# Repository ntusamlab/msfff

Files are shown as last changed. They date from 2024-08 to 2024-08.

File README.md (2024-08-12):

# minimizedsupportfff

## Project Title
Novel Fused Filament Fabrication System for Additive Manufacturing with Minimized Support Structures
<br />
<br />
## Project Description
The algorithm can modify the G-code to cooperate with the discrete platform, which includes support-eliminating, path-rearranging, and adding the lifting motions.
<br />
<br />
## File List and Descriptions
CAD_files:
| Name | Description |
| --- | --- |
| CAD_files | the whole model used in the program |
| fan_holder | the extruder module |
| modules | the servo and other ready-made parts |
| plane_unit | the part of the platform |
| ladder/bridge/blade | the part of case study |
| code | the whole code in algorithm |
| test_main | main program to modify g-code |
| test_3dprint_arduino | program to start the printing and communicate with printer |
| test_platform_raise_correction | correction g-code before printing |
| requirements | library for python |
| module | all functions required |
| test_table | database of the experiment |
<br />
<br />

## Steps 

Steps in order to run the code. 

1. please start from downloading or cloning the repository and all the way to run the code with required input data
2. use Cura to slice the stl. file and save the result into the 'gcode_cura'
3. run 'test_main.py' to modify the g-code and the result will automatically saved into 'test_output'
4. put the modified g-code into the SD card and set it into the printer
5. run 'test_3dprint_arduino.py' to start printing
6. The printer will pause as the platform is going to be lifted
7. after printing, the total time and support time will be shown

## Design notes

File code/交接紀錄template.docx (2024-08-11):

紀錄之前請將紅色說明文字刪除

研究題目/儀器種類：

研究題目名稱或儀器名稱(請註記產編)

記錄日期：

記錄人員與聯絡資訊：

原負責人與記錄人員名字與聯絡資訊(email)

原負責人：黃中道 r11522715@ntu.edu.tw

操作事前準備(硬體)：

需要操作系統前之準備(著重在硬體部分 例如燈光或背景等) 若無則寫無

操作事情準備(軟體)：

需要操作系統前之準備(著重在軟體部分) 若無則寫無

原負責人請將最後版本的軟體與所用到的照片/數據放到github並附上下載網址

交接的人請務必下載好最後版本的軟體與所用到的照片/數據

**8/12號老師會說明github管理

系統操作步驟：

請詳細記錄每一步 包含從開哪個程式 先處理哪個檔案

到如何操作整個系統 如何「收集」、「處理」與「紀錄」數據

每一步可以的話請附上圖片

特別須知/發生過的問題：

若曾經發生過特別的問題或是特殊的操作要點請詳細記錄

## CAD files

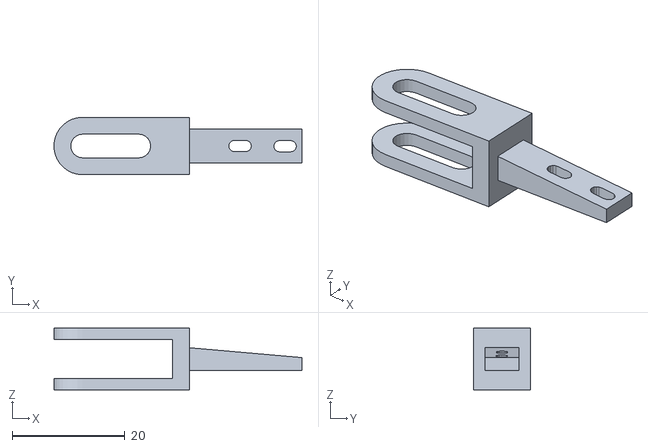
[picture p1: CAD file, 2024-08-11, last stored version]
CAD_files/fan_holder_0227/fan_holder_0301_05.stl
44.1 x 10.2 x 11.0

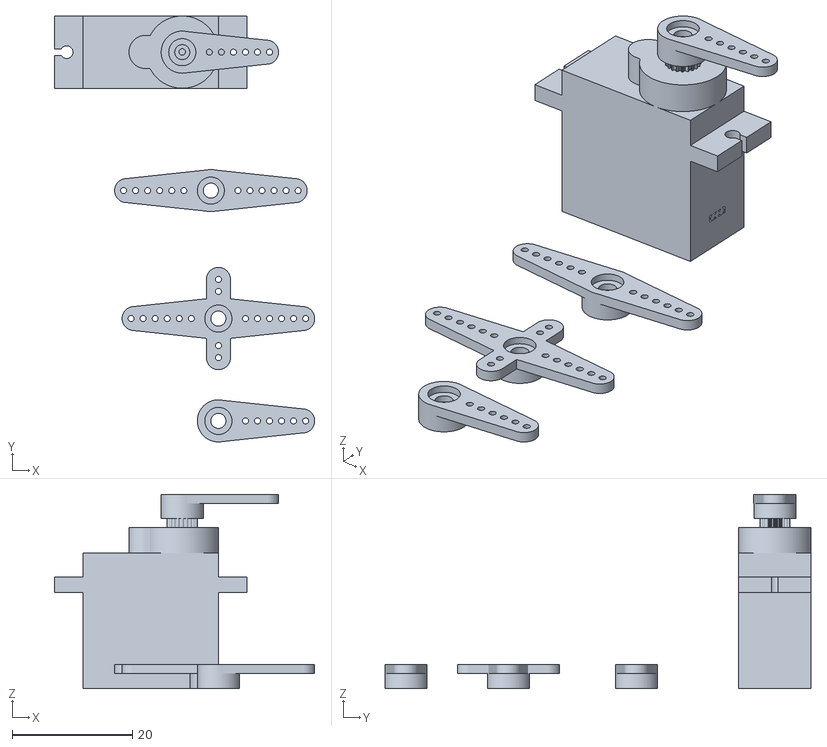
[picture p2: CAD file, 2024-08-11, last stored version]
CAD_files/modules/Servo SG90 Model.stl
43.2 x 70.8 x 32.2

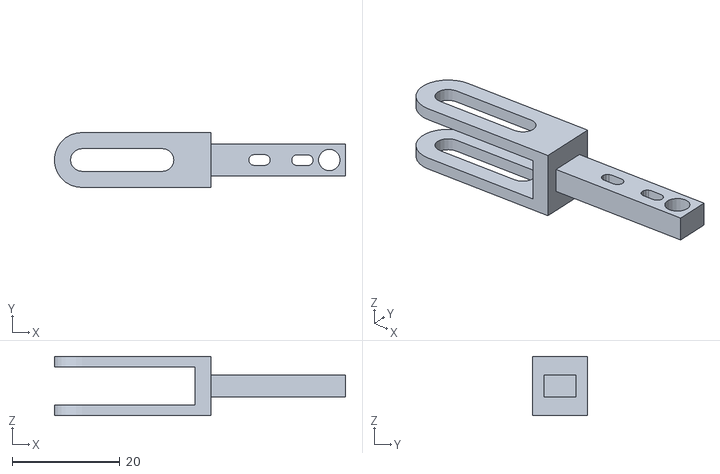
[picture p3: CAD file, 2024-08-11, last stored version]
CAD_files/fan_holder_0227/fan_holder_0301.stl
54.1 x 10.2 x 11.0

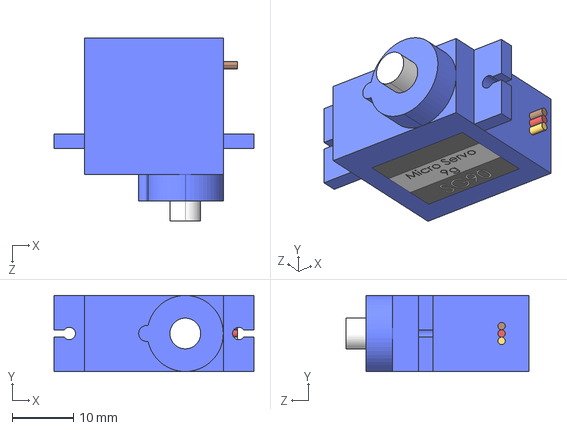
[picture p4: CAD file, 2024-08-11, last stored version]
CAD_files/modules/SG90 Micro Servo - 3D Model.STEP
32.6 x 12.4 x 29.9 mm

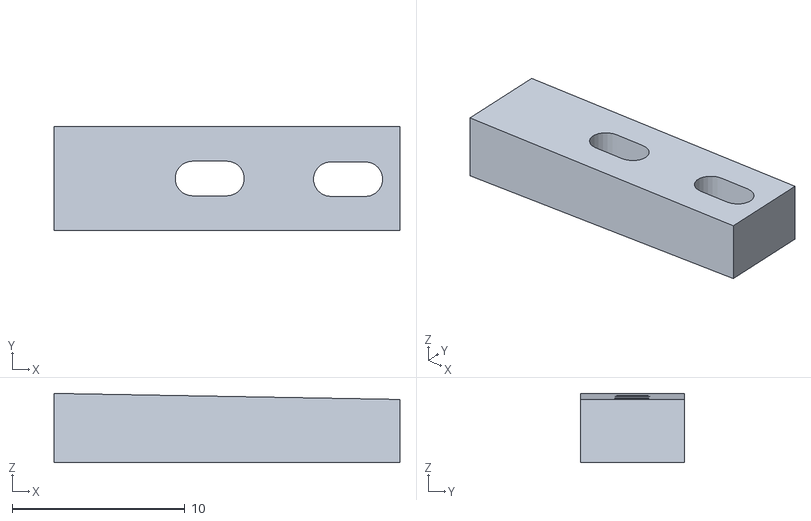
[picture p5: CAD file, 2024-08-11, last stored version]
CAD_files/fan_holder_0227/fan_holder_0301_01.stl
20.0 x 6.00 x 4.00

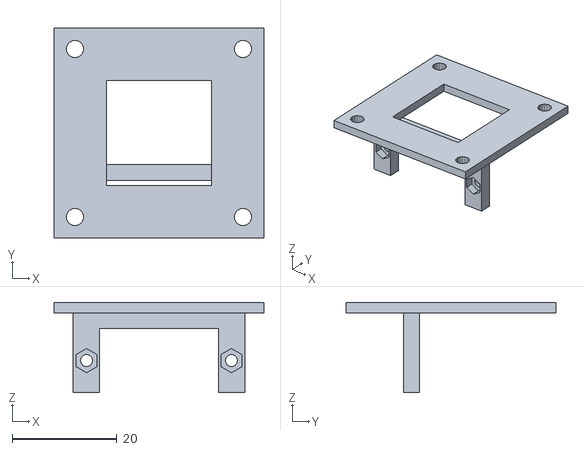
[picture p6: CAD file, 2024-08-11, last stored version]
CAD_files/fan_holder_0227/SG90_holder_0213.stl
40.0 x 40.0 x 17.2

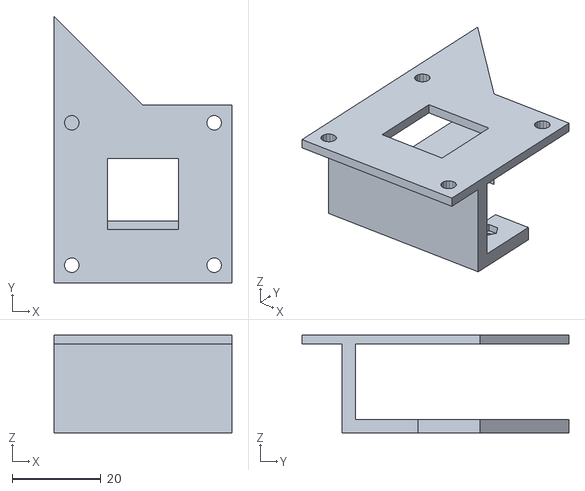
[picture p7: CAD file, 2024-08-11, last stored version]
CAD_files/fan_holder_0227/SG90_holder_0206.stl
40.0 x 60.0 x 22.0

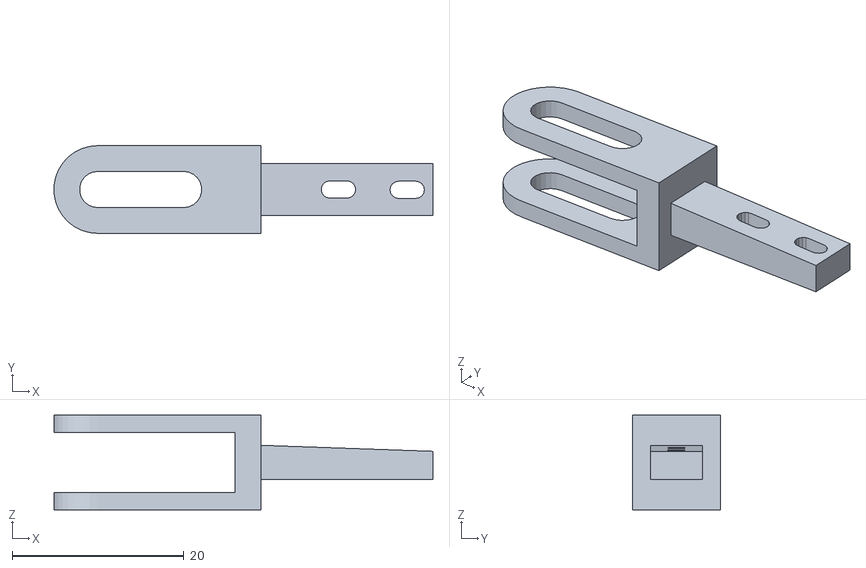
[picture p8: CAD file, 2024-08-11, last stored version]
CAD_files/fan_holder_0227/fan_holder_0301_02.stl
44.1 x 10.2 x 11.0

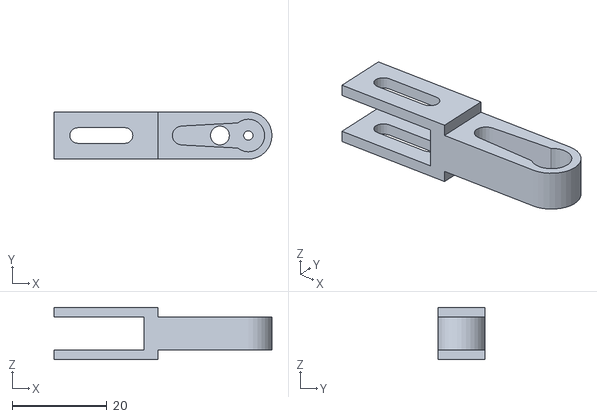
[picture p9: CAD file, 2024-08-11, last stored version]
CAD_files/fan_holder_0227/fan_holder_0301_10.stl
46.0 x 10.0 x 11.0

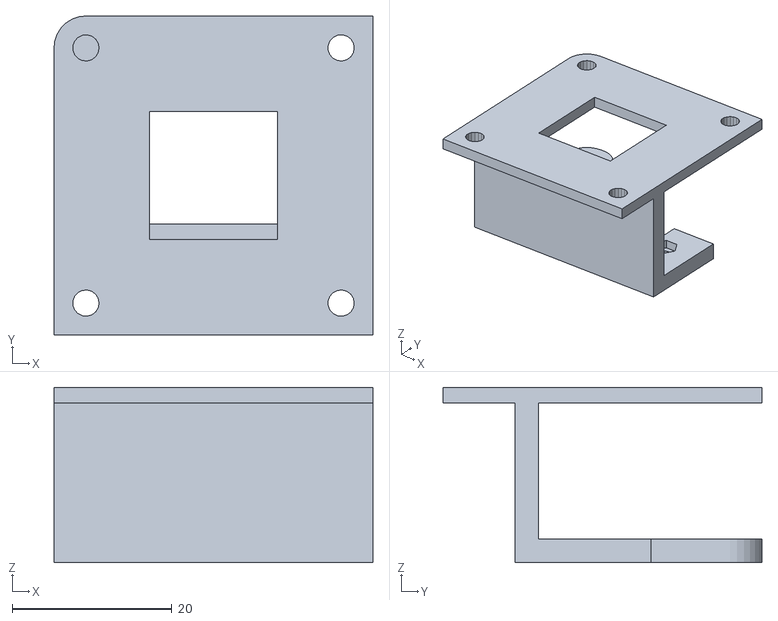
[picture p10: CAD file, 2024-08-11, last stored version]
CAD_files/fan_holder_0227/SG90_holder_1205.stl
40.0 x 40.0 x 22.0

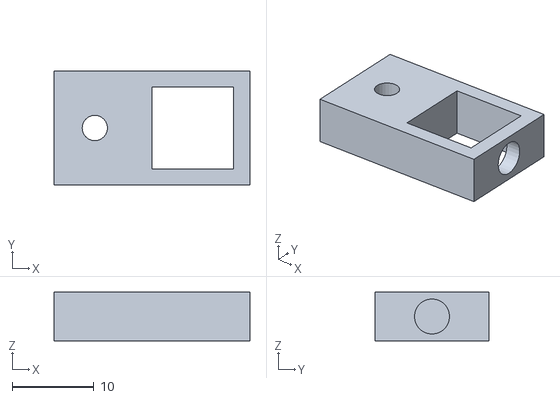
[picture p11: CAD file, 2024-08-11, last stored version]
CAD_files/fan_holder_0227/elemagnetic_holder_0306.stl
24.0 x 14.0 x 6.00

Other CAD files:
CAD_files/fan_holder_0227/fan_holder_0301_03.stl
CAD_files/fan_holder_0227/fan_holder_0301_04.stl
CAD_files/fan_holder_0227/fan_holder_0301_6.stl
CAD_files/Template_ladder_2.ipt
CAD_files/bridge_rect_final.ipt
CAD_files/fan_holder_0227/OldVersions/SG90 - Micro Servo 9g - Tower Pro.2_Pe_a.0002.ipt
CAD_files/fan_holder_0227/OldVersions/SG90_holder_0213.0032.ipt
CAD_files/fan_holder_0227/OldVersions/SG90_holder_1205.0021.ipt
CAD_files/fan_holder_0227/OldVersions/fan_holder_0130.0006.iam
CAD_files/fan_holder_0227/OldVersions/fan_holder_0216.0008.iam
CAD_files/fan_holder_0227/OldVersions/fan_holder_0227.0011.iam
CAD_files/fan_holder_0227/OldVersions/fan_holder_0301.0027.ipt
CAD_files/fan_holder_0227/SG90 - Micro Servo 9g - Tower Pro.1_Pe_a.ipt
CAD_files/fan_holder_0227/SG90 - Micro Servo 9g - Tower Pro.2_Pe_a.ipt
CAD_files/fan_holder_0227/SG90_holder_0213.ipt
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

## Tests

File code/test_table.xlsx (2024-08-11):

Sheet: database0126
No. | ratio |  | optimize-parameter(x,y,t) |  |  | time(s) |  | material(g)
 |  |  | x(mm) | y(mm) | t(degree) | total time | sup time | total material | sup material
40 |  | 10 | 76.5 | 41.8 | 0 | 11582.59227 | 2320.270777
2 | 18 | o | 100.98 | 77.3 | 1.8 | 60853.02281 | 27881.13442 | 161.42 | 65.08
3 | 10 | o | 76.5 | 41.8 | 0 | 15162.82971 | 5901.446297 | 35.78 | 11.76
4 | 12 | o | 77.52 | 78.54 | -9 | 21853.39851 | 8230.519028 | 55.67 | 19.65
5 | 12 | o | 77.52 | 78.54 | -9 | 21845.5783 | 8222.653735 | 53.46 | 18.54
6 | 12 | o | 77.52 | 78.54 | -9 | 21844.12758 | 8222.523314 | 55.28 | 19.15
7 | 10 | o | 76.5 | 41.8 | 0 | 15156.89194 | 5893.583755 | 35.37 | 11.79
9 | 14 | o | 61.2 | 90 | 0 | 32739.07891 | 13773.96574 | 81.8 | 30.41
12 | 16 | o | 86.7 | 75.4 | 9 | 43748.2426 | 18310.66127 | 112.34 | 42.48
16 | 10 | o | 76.5 | 41.8 | 0 | 15156.84602 | 5893.548965 | 35.28 | 11.75
17 | 18 | o | 100.98 | 77.3 | 1.8 | 60845.99663 | 27874.10117 | 152.38 | 61.51
18 | 16 | o | 86.7 | 75.4 | 9 | 43763.64611 | 18322.85825 | 110.61 | 41.73
19 | 14 | o | 61.2 | 90 | 0 | 32754.47977 | 13783.18366 | 79.93 | 29.69
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

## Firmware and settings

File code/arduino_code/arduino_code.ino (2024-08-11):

#include <Servo.h>

Servo servo;
String str;

void setup() {
  // put your setup code here, to run once:
  servo.attach(9);
  pinMode(12,OUTPUT);
  Serial.begin(9600);
  servo.write(120);
  digitalWrite(12,LOW);
}

void loop() {
  // put your main code here, to run repeatedly:
  if(Serial.available()){
    str=Serial.readStringUntil('\n');
    if(str=="down"){
      servo.write(0);
      digitalWrite(12,HIGH);
    }else if(str=="up"){
      servo.write(120);
      digitalWrite(12,LOW);
    }
  }
}

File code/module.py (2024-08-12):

import matplotlib.pyplot as plt
import numpy as np
import copy
import serial
import time
import math
import openpyxl
import os

# parameters
# length/e=0.001, e=mm
err=1e-4
d_platform=0.1
layer_height=0.28
ratio_e_xy=0.046564
drawback=6.5
z0=110
z_init=106

nx=4
ny=4
lx=51
ly=51
gap=lx-50


# file in/output

def get_gcode(filename):
    """
    Turn the gco. file into a list
    """
    with open(filename, 'r') as f_gcode:
        data = f_gcode.read().split("\n")
    return data

def output_gcode(filename,gcode_list):
    '''
    save a list as a gco. file
    '''
    filepath='/'.join(filename.split('/')[:-1])
    if os.path.isdir(filepath) is False:
        os.makedirs(filepath)
    if not gcode_list:
        print("output_gcode: No gcode")
        return
    with open(filename, 'w') as f_gcode:
        for ele in gcode_list:
            f_gcode.write(ele+"\n")
    return

def output_excel(filename,parameters,new_value=None):
    '''
    edit the excel with new experiment data
    '''
    book = openpyxl.load_workbook(filename)
    sheet = book.active
    last_row=len(sheet['A'])
    while sheet.cell(row=last_row,column=1).value is None:
        last_row=last_row-1
    sheet.cell(row=last_row+1,column=1).value=int(last_row-1)
    for i,ele in enumerate(parameters):
        sheet.cell(row=last_row+1,column=i+2).value=float(ele)
    if new_value:
        for jele in new_value.split(','):
            sheet['{0}{1}'.format(jele[0],last_row+1)].value=float(jele[1:])
    else:
        sheet['F{0}'.format(last_row+1)].value='-'

    book.save(filename)

# function used in 3d print and arduino

def serWrite(ser,order):
    ser.write((order+'\r\n').encode('ascii'))
    time.sleep(1)

# function used in trim process

def nozzle_position_update(noz_end_pos=[0,0,0,0],gcode=None):
    # update nozzle position
    noz_init_pos=copy.deepcopy(noz_end_pos)
    g_point=gcode.split(' ')
    for igp in range(len(g_point)):
        if ';' in g_point[igp]:
            break
        if 'X' in g_point[igp]:
            noz_end_pos[0]=float(g_point[igp][1:])
        if 'Y' in g_point[igp]:
            noz_end_pos[1]=float(g_point[igp][1:])
        if 'Z' in g_point[igp]:
            noz_end_pos[2]=float(g_point[igp][1:])
        if 'E' in g_point[igp]:
            noz_end_pos[3]=float(g_point[igp][1:])
    return noz_init_pos,noz_end_pos

def line_cross2(p1,p2,lx=lx,ly=ly):
    points=[]

    # define the slope of the line from p1 to p2
    m=float('inf') if abs(p1[0]-p2[0])<err else (p1[1]-p2[1])/(p1[0]-p2[0])
    def funcy(ix):
        return (ix-p1[0])*m+p1[1]
    def funcx(iy):
        return (iy-p1[1])/m+p1[0]
    
    # let the points sorted by the value of x
    (px1,px2)=(p2,p1) if p1[0]>p2[0] else (p1,p2)
    
    # generate the intersections along the x-axis
    xcoor=[]
    for ix in range(math.floor((px1[0]-gap)/lx)-1,math.ceil((px2[0]+gap)/lx)+1):
        xi=ix*lx
        xcoor.extend([xi-gap,xi+gap])
    points.extend([[ele_x,funcy(ele_x)]for ele_x in xcoor if (px1[0]-ele_x)*(px2[0]-ele_x)<0])

    # let the points sorted by the value of y
    (py1,py2)=(p2,p1) if p1[1]>p2[1] else (p1,p2)

    # generate the intersections along the y-axis
    ycoor=[]
    for iy in range(math.floor((py1[1]-gap)/ly),math.ceil((py2[1]+gap)/ly)):
        yi=iy*ly
        ycoor.extend([yi-gap,yi+gap])
    points.extend([[funcx(ele_y),ele_y]for ele_y in ycoor if (py1[1]-ele_y)*(py2[1]-ele_y)<0])


    def same_platform(p,l,gap):
        return p[0]%l>gap and p[0]%l<l-gap and p[1]%l>gap and p[1]%l<l-gap
    if same_platform(p1,lx,gap):
        points.append(p1)
    if same_platform(p2,ly,gap):
        points.append(p2)

    sorted_points=sorted(points, key=lambda points: points[0]) if abs(p1[0]-p2[0])>err else sorted(points, key=lambda points: points[1])
    if p1[0]-p2[0]>err or p1[1]-p2[1]>err:
        sorted_points.reverse()

    return sorted_points

def gcode_raise(coor_orig,z_target,coor_comp=[5,49,56.3],suck_comp=-2):
    # 25,25,111.3 32,77,137.8
    # coor_comp = distance between magnetic and nozzle
    # coor_comp[2]-suck-comp[3]=comp for suck and for lift

    plane_height_comp=[
        [0.4,0.7,0.4,0.4],
        [-0.4,-0.2,0.2,-0.4],
        [-0.2,0.0,-0.2,0.2],
        [-0.2,-0.4,-0.2,0.4],
        ]
    plane_side_comp=[
        [10,0,0,0],
        [10,10,10,10],
        [10,10,10,10],
        [10,10,10,0]
        ]

    raise_gcode=[
        # move to the point above the certain platform unit
        "G0 F9000 X{0} Y{1} Z{2}".format(coor_orig[0]+coor_comp[0]+plane_side_comp[math.floor(coor_orig[0]/lx)][math.floor(coor_orig[1]/ly)],coor_orig[1]+coor_comp[1],z_target+coor_comp[2]+20),
        # send message "down" back to pc
        "M0 P500",
        "M118 A1 down",
        # 1.5s wait for motor movement
        "M0 S1.5",
        "G0 F9000 Z{0}".format(coor_orig[2]+coor_comp[2]+suck_comp),
        "G0 F9000 Z{0}".format(z_target+coor_comp[2]+plane_height_comp[math.floor(coor_orig[0]/lx)][math.floor(coor_orig[1]/ly)]),
        "M0 P500",
        "M118 A1 up",
        "M0 S1.5"
        ]
    return raise_gcode

def fix_gcode(gcode_line,fix_para_arr):
    gcode_unit_arr=gcode_line.split(' ')  
    for i,ele in enumerate(gcode_unit_arr):
        startword=ele[0] if ele[0] else None
        match startword:
            case ';':
                break
            case 'X'|'Y'|'Z'|'E'|'G'|'F':
                fix_number=[e[1:] for e in fix_para_arr if startword in e]
                if fix_number:
                    if abs(float(fix_number[0])+1)<err:
                        gcode_unit_arr[i]=''
                        continue
                    gcode_unit_arr[i]='{0}{1:.5f}'.format(startword,float(fix_number[0])) if startword != 'G' else '{0}{1}'.format(startword,int(fix_number[0]))
            case _:
                pass
                
    fixed_gcode=" ".join(gcode_unit_arr)
    return fixed_gcode

# function varify
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

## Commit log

2024-08-11 1st push
    [test_table.xlsx]
2024-08-11 CAD update
    [SG90 - Micro Servo 9g - Tower Pro.1_Pe_a-LAPTOP-JJ948SAV.ipt, SG90 - Micro Servo 9g - Tower Pro.1_Pe_a.ipt, SG90 - Micro Servo 9g - Tower Pro.2_Pe_a-LAPTOP-JJ9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]
